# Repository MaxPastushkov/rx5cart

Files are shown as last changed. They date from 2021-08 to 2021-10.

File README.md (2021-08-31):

# RX5Cart
A replacement for the Yamaha RAM4 cartridge, based on [GliGli's RX5USB](https://github.com/gligli/rx5usb)

**WARNING: This project is currently incomplete. Do not use the board yet! The PCB and firmware have not been tested!**

* `board_sch` - board and schematic files for KiCad
* `rx5cart.ino` - firmware for the teensy
* `transfer.py` - software for interfacing to the RX5Cart

### Loading the firmware ###
You will need Teensyduino. Download and instructions are [here](https://www.pjrc.com/teensy/td_download.html).

Open the `rx5cart.ino` file in the Arduino software, plug in the teensy, and press Upload.

### Using the transfer software ###
* You will need Python 3 and the `pyserial` package.
* To read RAM into a file, use `python transfer.py -r file.bin`
* To write to RAM from a file, use `python transfer.py -w file.bin`
* By default it uses the device `/dev/ttyACM0`. You can use the `-d` flag to change it.

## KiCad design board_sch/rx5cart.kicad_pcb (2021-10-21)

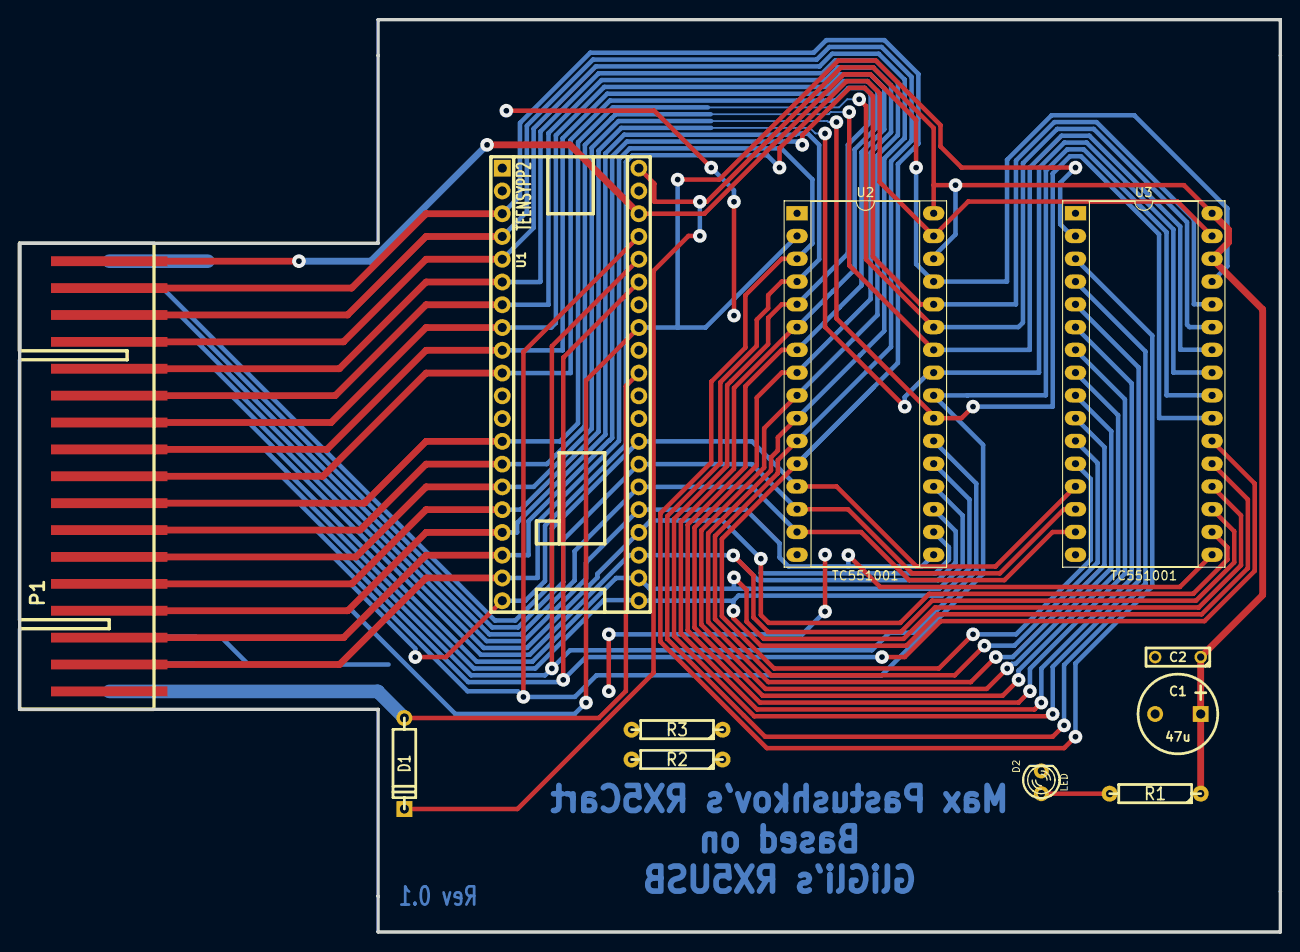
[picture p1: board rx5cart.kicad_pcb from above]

Board: 2 copper layers, 140.7 x 101.8 mm, 11 parts (0 on the bottom side), 33 nets.

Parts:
C1: 47u; C1
C2: 100n; C2
D1: 1N5817
D2: LED; LED-3MM
P1: RX5_WDC; RX5_WDC_CART
R1: 470; RESISTOR
R2, R3: 10k; RESISTOR
U1: TEENSYPP2
U2, U3: TC551001

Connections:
/A0: P1.A0, U1.3, U2.12, U3.12
/A1: P1.A1, U1.4, U2.11, U3.11
/A2: P1.A2, U1.5, U2.10, U3.10
/A3: P1.A3, U1.6, U2.9, U3.9
/A4: P1.A4, U1.7, U2.8, U3.8
/A5: P1.A5, U1.8, U2.7, U3.7
/A6: P1.A6, U1.9, U2.6, U3.6
/A7: P1.A7, U1.10, U2.5, U3.5
/A8: P1.A8, U1.13, U2.27, U3.27
/A9: P1.A9, U1.14, U2.26, U3.26
/A10: P1.A10, U1.15, U2.23, U3.23
/A11: P1.A11, U1.16, U2.25, U3.25
/A12: P1.A12, U1.17, U2.4, U3.4
/A13: P1.A13, U1.18, U2.28, U3.28
/A14: P1.A14, U1.19, U2.3, U3.3
/A15: P1.A15, U1.20, U2.31, U3.31
/A16: P1.A16, U1.45, U2.2, U3.2
/CE0: P1.CE0, R3.1, U1.48, U2.22
/CE1: P1.CE1, R2.1, U1.47, U3.22
/D0: P1.D0, U1.40, U2.13, U3.13
/D1: P1.D1, U1.39, U2.14, U3.14
/D2: P1.D2, U1.38, U2.15, U3.15
/D3: P1.D3, U1.37, U2.17, U3.17
/D4: P1.D4, U1.36, U2.18, U3.18
/D5: P1.D5, U1.35, U2.19, U3.19
/D6: P1.D6, U1.34, U2.20, U3.20
/D7: P1.D7, U1.33, U2.21, U3.21
/OE: P1.OE, U1.49, U2.24, U3.24
/WE: P1.WE, U1.50, U2.29, U3.29
GND: C1.2, C2.2, D2.2, P1.CT0, P1.CT1, P1.GND, U1.1, U1.42, U2.16, U3.16
unnamed: D1.1, P1.+5V, U1.43
unnamed: D2.1, R1.2
VCC: C1.1, C2.1, D1.2, R1.1, R2.2, R3.2, U1.52, U2.30, U2.32, U3.30, U3.32

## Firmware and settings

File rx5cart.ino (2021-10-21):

#include <CRC32.h>
#include <SoftwareSerial.h>

/* Data needs to be transfered in blocks, because the
   teensy only has 8k of RAM, but we need 128k */
#define BLOCKSIZE 0x1000

#define RX5DETECT 18 // PE6
#define WE 25 // PB5
#define OE 24 // PB4
#define CE0 23 // PB3
#define CE1 22 // PB2
#define A16 20 // PB0

unsigned char readRAM(uint32_t addr);
void writeRAM(uint32_t addr, unsigned char data);

SoftwareSerial debugSer = SoftwareSerial(19, 9); // 19 is unused

bool freeze = false;

void setup() {

  Serial.begin(115200);
  Serial.setTimeout(30000);

  pinMode(8, OUTPUT); // PE0
  digitalWrite(8, LOW); // Ground
  
  pinMode(9, OUTPUT); // PE1
  debugSer.begin(9600);

  pinMode(RX5DETECT, INPUT);
}

void loop() {

  // Release bus and wait
  if (freeze) {
    while (1);
  }

  // Disable everything
  PORTB = 0b00111100;

  char operation;

  debugSer.println("Waiting for unplug and start symbol...");

  // Get start signal
  while (1) {

    if (digitalRead(RX5DETECT)) {
      Serial.read(); // Clear buffer
      continue;
    }
    
    if (Serial.available()) {
      operation = Serial.read();
      break;
    }
  }
//  while (!Serial.available() || digitalRead(RX5DETECT));
//  
//  
//  char operation = Serial.read();

  // Set ports B, C, D to output
  DDRB = 0xFF;
  DDRC = 0xFF;
  DDRD = 0xFF;

  CRC32 crc;
  char buff[BLOCKSIZE];

  if (operation == 'r') {

    debugSer.println("Reading data...");

    // Read block
    for (unsigned int i = 0; i < 0x20000 / BLOCKSIZE; i++) {
      for (unsigned int j = 0; j < BLOCKSIZE; j++) {
        buff[j] = readRAM((uint32_t)i * BLOCKSIZE + j);
        crc.update(buff[j]); // Add to CRC buffer
      }

      Serial.write(buff, BLOCKSIZE);
    }

    debugSer.println("Read data");
    
    // Get checksum
    while (!Serial.available());
    debugSer.println("Serial available");
    uint32_t remotecrc = 0;
    debugSer.print("Read bytes: ");
    debugSer.println(Serial.readBytes((char *)&remotecrc, 4));

    debugSer.print("Read checksum: ");
    debugSer.println((unsigned long) remotecrc);

    uint32_t validcrc = crc.finalize(); // Calculate checksum
    debugSer.println("Calculated checksum");
    
    if (remotecrc == validcrc) {
      Serial.write(1);
      debugSer.println("All good!");
    } else {
      Serial.write(2);
      debugSer.println("Checksums don't match");
    }
    
  } else if (operation == 'w') {

    debugSer.println("Receiving data...");

    uint32_t pos = 0;

    //for (unsigned int i = 0; i < 0x20000; i++) {
    while (pos < 0x20000) {

      unsigned int bytesavailable = 0;
      while (!(bytesavailable = Serial.available()));
      Serial.readBytes(buff, bytesavailable); // Receive block

      //writeRAM(0, 0xAA);
  
      // Write block
      for (unsigned int j = 0; j < bytesavailable; j++) {
        writeRAM(pos+j, buff[j]);
        crc.update(buff[j]); // Add to CRC buffer
      }

      pos += bytesavailable;

      Serial.write(1); // Acknowledgement
    }

    debugSer.println("Calculating checksum...");
    uint32_t mycrc = crc.finalize(); // Calculate checksum
    
    debugSer.print("Sending checksum: ");
    debugSer.println(mycrc);
    
    Serial.write((char *)&mycrc, 4);

    debugSer.println("Done!");
    
    //debugSer.println(readRAM(0), HEX);

  }
  
  // Reset pins
  DDRB = 0x00;
  DDRC = 0x00;
  DDRD = 0x00;
  DDRF = 0x00;
  PORTC = 0b00000000;
  PORTD = 0b00000000;
  PORTF = 0b00000000;

  // Pull up pins
  PORTB = 0b00111100;

  //freeze = true;
}

unsigned char readRAM(uint32_t addr) {
  
  bool a16 = (addr >> 16) & 0x1;
  bool a17 = (addr >> 17) & 0x1;

  digitalWrite(WE, HIGH);
  digitalWrite(OE, LOW);
  
  digitalWrite(CE0, a17);
  digitalWrite(CE1, !a17);
  
  DDRF = 0x00; // Set data pins to input

  PORTD = addr & 0xFF; // Set lower byte of address
  PORTC = (addr >> 8) & 0xFF; // Set upper byte of address
  digitalWrite(A16, a16); // Set last bit

  return PINF; // Return data
}

void writeRAM(uint32_t addr, unsigned char data) {
  bool a16 = (addr >> 16) & 0x1;
  bool a17 = (addr >> 17) & 0x1;

  digitalWrite(OE, HIGH);

  digitalWrite(CE0, a17);
  digitalWrite(CE1, !a17);

  DDRF = 0xFF; // Set data pins to output

  // Set address
  PORTD = addr & 0xFF; // Set lower byte of address
  PORTC = (addr >> 8) & 0xFF; // Set upper byte of address
  digitalWrite(A16, a16); // Set last bit

  // Set data pins
  PORTF = data;

  // Write data
  digitalWrite(WE, LOW);
  digitalWrite(WE, HIGH);

  // Reset CE
  digitalWrite(CE0, HIGH);
  digitalWrite(CE1, HIGH);
}

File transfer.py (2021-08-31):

# Written by Max Pastushkov in August 2021

import serial
import sys, os, argparse
import zlib

# Due to size of serial buffer on teensy
write_blocksize = 64


def progressBar(current, total, barLength = 25):
    percent = (float(current) * 100 / total) + 1
    arrow   = '-' * int(percent/100 * barLength - 1) + '>'
    spaces  = ' ' * (barLength - len(arrow))

    print('Progress: [%s%s] %d %%' % (arrow, spaces, percent), end='\r')

operation = ""
filepath = ""
device = "/dev/ttyACM0"

parser = argparse.ArgumentParser()

parser.add_argument("-d", "--device", help="device file to use")

group = parser.add_mutually_exclusive_group(required=True)
group.add_argument("-r", "--read", help="file to read data into", metavar="<output file>")
group.add_argument("-w", "--write", help="file to write from", metavar="<input file>")

args = parser.parse_args()

if (args.read):
    operation = "wb"
    filepath = args.read
elif (args.write):
    operation = "rb"
    filepath = args.write
    
if (args.device):
    device = args.device

try:
    ser = serial.Serial(device, 115200)
except serial.SerialException as e:
    print("Error opening device: " + str(e))
    sys.exit(1)

buff = b''
    
try:
    with open(filepath, operation) as f:
        if operation == "wb":
            
            ser.write(b'r') # Send start signal
            
            print("Reading data...")
            buff = ser.read(0x20000) # Read data
            
            # Send checksum
            print("Calculating checksum...")
            crc = zlib.crc32(buff) & 0xFFFFFFFF
            print("Checksum is " + str(crc))
            
            print("Sending checksum...")
            ser.write(crc.to_bytes(4, "little"))
            
            print("Waiting for status...")
            status = ser.read(1)
            print("Received status: " + str(status))
            
            if status != b'\x01':
                print("Verification Error: checksum does not match")
                ser.close()
                sys.exit(1)
                
            f.write(buff) # Save data
            
            print("Successfully received data from device")
        
        elif operation == "rb":
            
            if os.path.getsize(filepath) != 0x20000:
                print("Error: invalid file size")
                ser.close()
                sys.exit(1)
            buff = f.read(0x20000)
            
            crc = zlib.crc32(buff) & 0xFFFFFFFF # Calculate checksum
            
            ser.write(b'w') # Send start signal
            
            print("Sending data...")
            for i in range(0, 0x20000, write_blocksize):
                blockbuff = buff[i:i+write_blocksize] # Get single chunk
                ser.write(blockbuff)
                ser.read(1) # Wait for acknowledgement
                progressBar(i, 0x20000)
            
            print("\nWaiting for checksum...")
            devicecrc = ser.read(4) # Get recipient checksum
            devicecrc = int.from_bytes(devicecrc, "little")
            print("Received checksum: " + str(devicecrc))
            
            if devicecrc != crc:
                print("Verification Error: checksum does not match")
                print("Expected: " + str(crc))
                ser.close()
                sys.exit(1)
            
            print("Successfully sent data to device")
        
except IOError as e:
    print("Could not open file: " + str(e))
    ser.close()
    sys.exit(1)

ser.close()

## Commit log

2021-08-27 Add all files
    [rx5cart.kicad_pcb, rx5cart.sch]
2021-08-28 Add RX5 power sense
    [rx5cart.kicad_pcb, rx5cart.sch]
2021-08-31 Change revision number
    [rx5cart.kicad_pcb]
2021-08-31 Fixed extra paste layer
    [rx5cart.kicad_pcb]
2021-08-31 Generate gerbers
    [rx5cart-B_Cu.gbl, rx5cart-B_Mask.gbs, rx5cart-Edge_Cuts.gm1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]
2021-09-02 Change ground plane
    [rx5cart-B_Cu.gbl, rx5cart-B_Mask.gbs, rx5cart-Edge_Cuts.gm1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]
2021-10-21 Unfinished PCB
    [rx5cart.kicad_pcb, rx5cart.sch]
